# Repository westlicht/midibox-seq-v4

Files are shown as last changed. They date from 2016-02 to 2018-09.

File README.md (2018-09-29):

# midibox-seq-v4

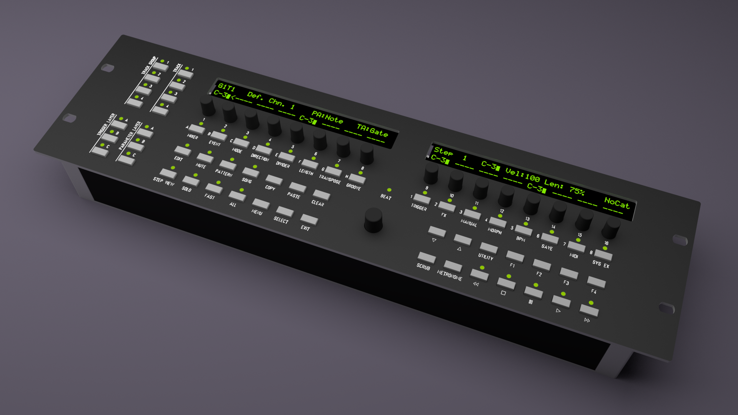
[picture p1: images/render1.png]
Rendering


This repository contains some documentation and data created during the build process of a MIDIBox SEQ V4. Please note that I'm **not** the original author of the project. The original project is hosted at http://ucapps.de

## MIDIbox PCBs

I ordered the PCBs from http://midiboxshop.bigcartel.com

Here is the list:

- 1x [CORE STMF32 BOARD](http://midiboxshop.bigcartel.com/product/core-stm32f4-board)
- 2x [MIDI I/O MODULE BOARD](http://midiboxshop.bigcartel.com/product/midi-i-o-module-board)
- 1x [DOUT MODULE BOARD](http://midiboxshop.bigcartel.com/product/dout-module-board)
- 1x [AOUT_NG BOARD](http://midiboxshop.bigcartel.com/product/aout_ng-module-board)
- 1x [SEQ CS BOARD](http://midiboxshop.bigcartel.com/product/seq-cs-board)

## Parts

I ordered the parts from [TME](http://www.tme.eu/en), [Reichelt](http://www.reichelt.com/), [DigiKey](http://www.digikey.com) and [Mouser](http://www.mouser.com). Sourcing the parts is a little painful. In addition, for some parts there are a few (or many) options. The following are a few notes on the parts I've chosen for the build:

- ALPS [Reichelt](https://www.reichelt.com/Drehimpulsgeber/STEC12E08/3/index.html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)
TODO

## Custom PCB

As I wanted to have nice backpanel as well as Ethernet support, I designed a PCB with the following additional features:

- Ethernet via SPI (based on http://ucapps.de/mbhp_eth.html)
- SD card socket
- USB connector
- +/- 12V DC/DC converter for the AOUT power supply

The PCB was designed in [KiCad](http://kicad-pcb.org/) and produced by [OSH Park](https://oshpark.com/). The PCB is available [here](https://oshpark.com/shared_projects/DuxxcHS7). Feel free to order your own!

Here is the bill of materials:

| Part | Description | Supplier |
| --- | --- | --- |
| C1, C4, C5, C6, C8, C9, C10, C11, C14, C15 | Ceramic Capacitor 100 nF |
| C2, C3 | Ceramic Capacitor 18 pF |
| C7 | Tantal Capacitor 10 uF |
| C12, C16 | Polarized Capacitor 47 uF |
| C13 | Polarized Capacitor 100 uF |
| R1 | Resistor 2.32 kOhm |
| R2, R3, R4, R5 | Resistor 49.9 Ohm |
| R6, R7 | Resistor 220 Ohm |
| L1 | Ferrit Bead 10 uH | [Reichelt](https://www.reichelt.com/Filter/BEAD-10-60/3/index.html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) |
| Y1 | Crystal 25 MHz | [Reichelt](https://www.reichelt.com/Quarze/25-0000-HC49U-S/3/index.html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) |
| IC1 | ENC28J60-I/SP DIP | [DigiKey](http://www.digikey.ch/product-detail/de/ENC28J60-I%2FSP/ENC28J60-I%2FSP-ND/1680061) |
| P1 | USB B connector | TODO |
| U1 | 3M SD-RSMT-2-MQ | [Mouser](http://www.mouser.ch/ProductDetail/3M-Electronic-Solutions-Division/SD-RSMT-2-MQ/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) |
| U2 | NMH0512SC ([datasheet](http://www.farnell.com/datasheets/1790401.pdf)) | [Reichelt](https://www.reichelt.com/Wandler-Module-DC-DC/NMH0512SC/3/index.html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)
| U3 | Pulse J0026D21E | [Mouser](http://www.mouser.ch/search/ProductDetail.aspx?r=673-J0026D21E) |

## Frontpanel / Case

Frontpanel

Backpanel

The frontpanel is based on the [Wilba frontpanel](http://www.midibox.org/dokuwiki/doku.php?id=wilba_mb_seq). I only adjusted some of the drillings in addition to moving things around slightly to make sure everything fits within the case. The backpanel was designed from scratch in order to fit nicely with the MIDI I/O PCBs as well as my own PCB. In addition, a DSUB-25 connector is used for the analog bus and a few important analog outputs are available seperatly on 3.5 mm jacks. The rest of the case are just basic aluminium panels and everything is hold together by enclosure profiles. The case can be ordered from [Schaeffer AG](https://www.schaeffer-ag.de). All required files are available in the ``case`` directory.

## Notes

## Links

## Build Images

Build
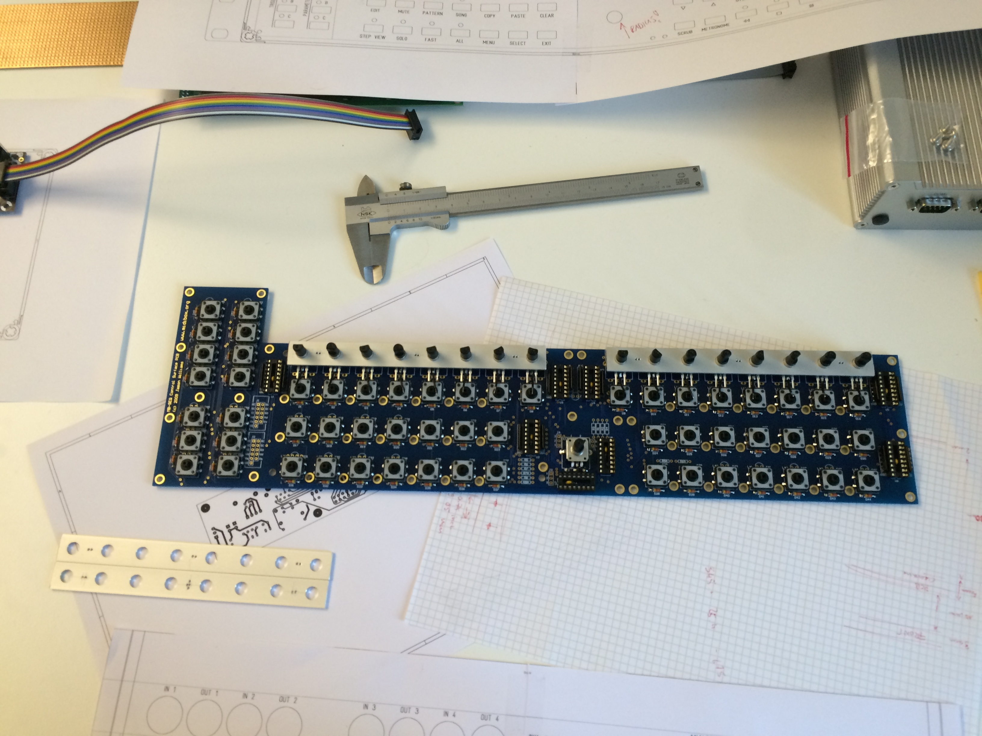
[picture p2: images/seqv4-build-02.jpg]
Build

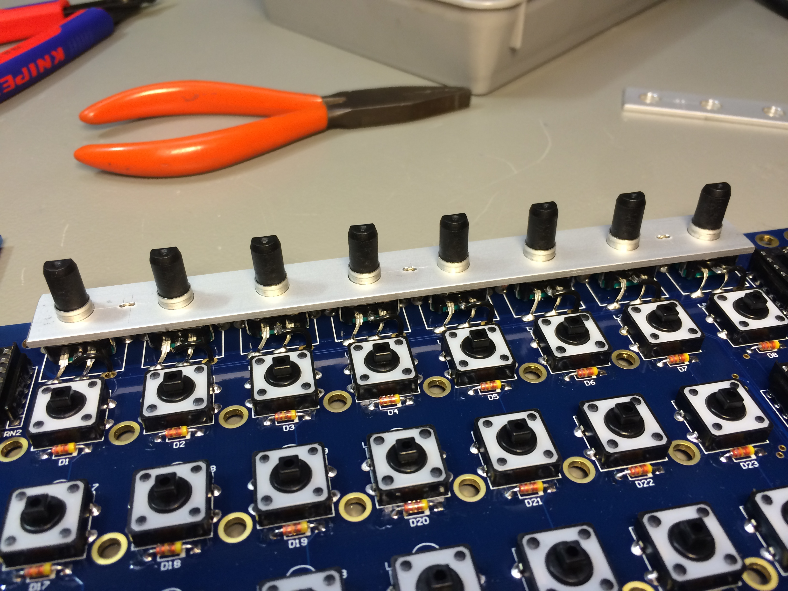
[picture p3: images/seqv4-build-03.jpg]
Build

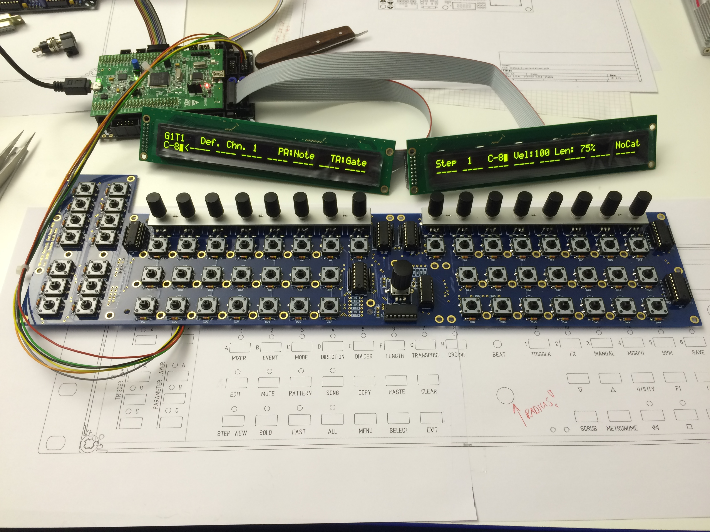
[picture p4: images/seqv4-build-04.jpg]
Build

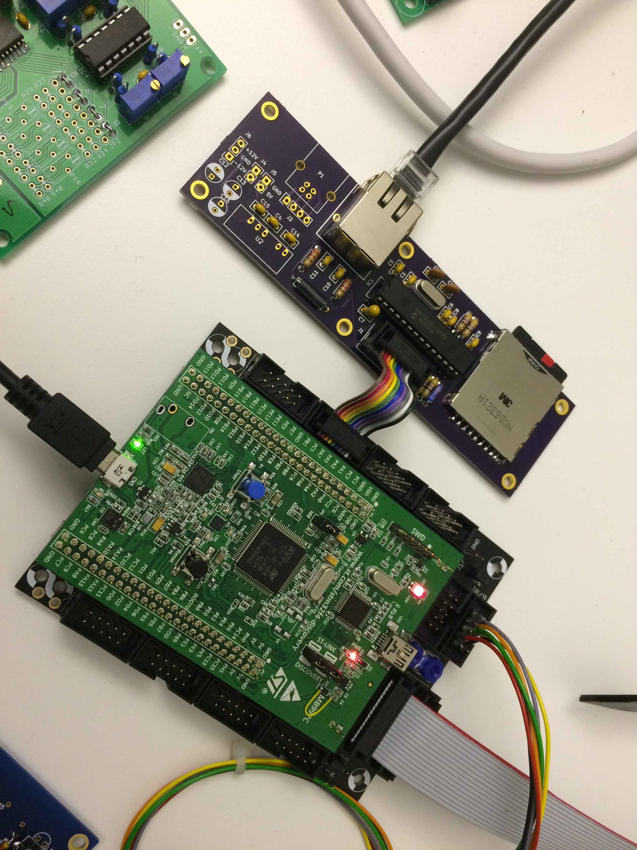
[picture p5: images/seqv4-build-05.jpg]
Build

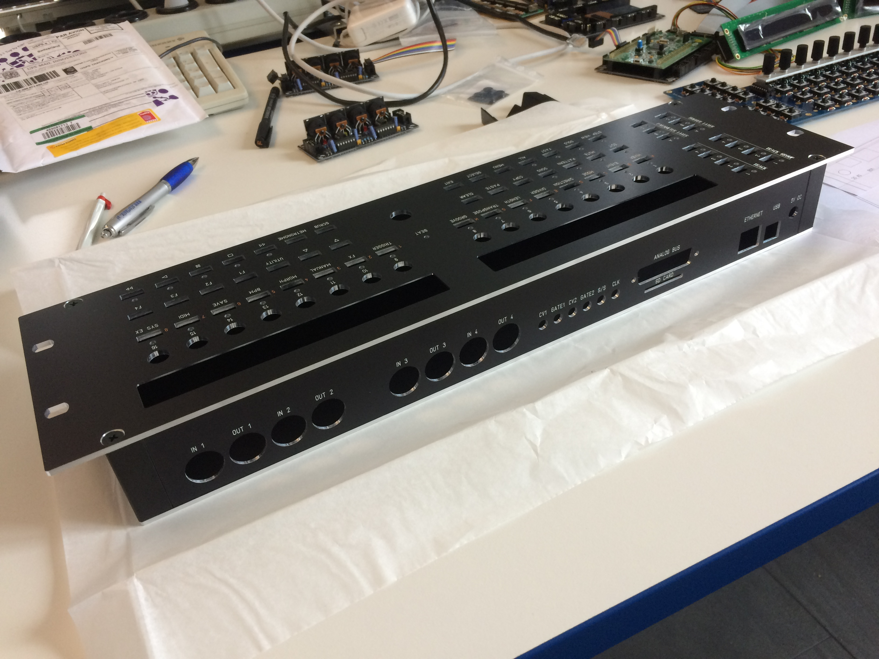
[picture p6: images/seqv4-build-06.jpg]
Build

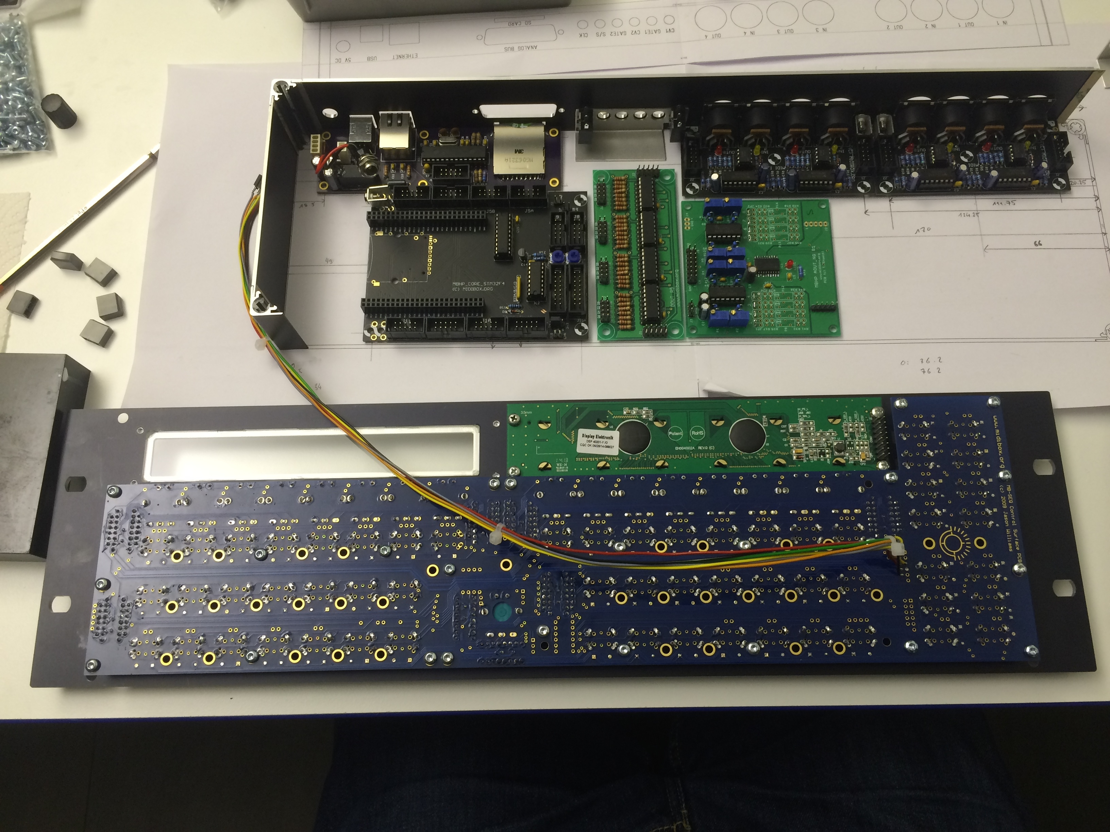
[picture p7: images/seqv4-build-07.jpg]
Build

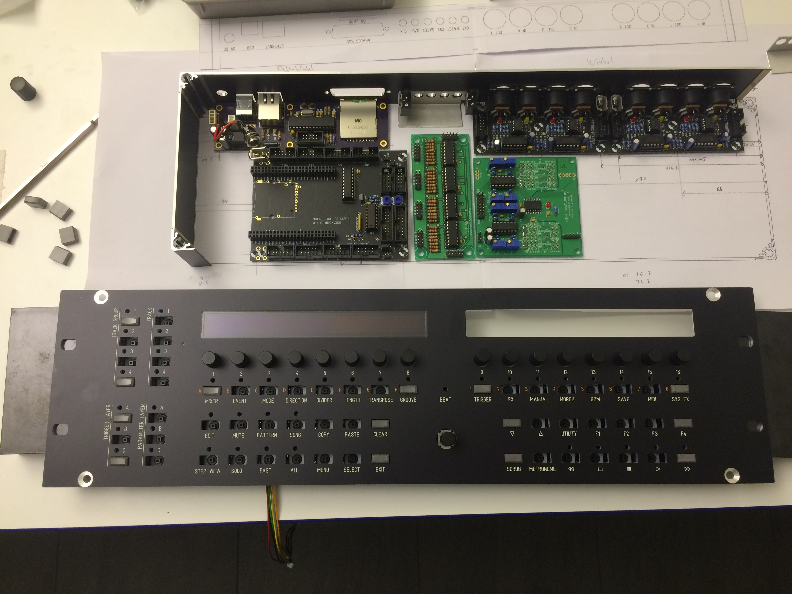
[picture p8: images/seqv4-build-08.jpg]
Build

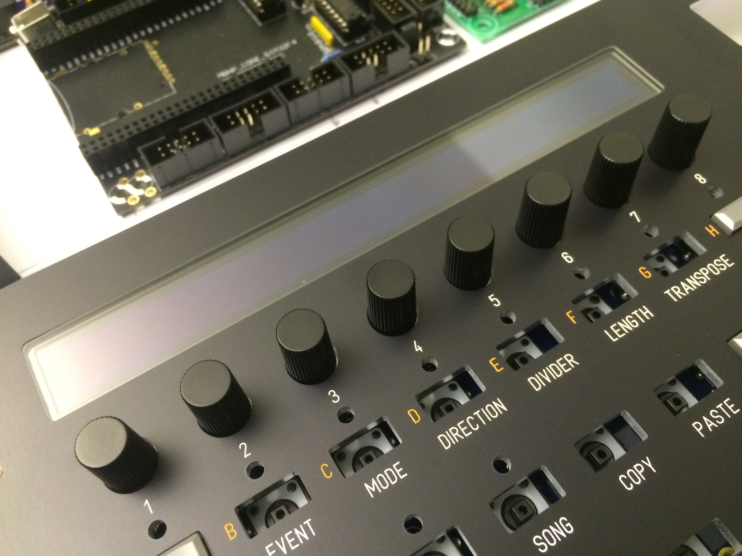
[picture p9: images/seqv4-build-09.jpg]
Build

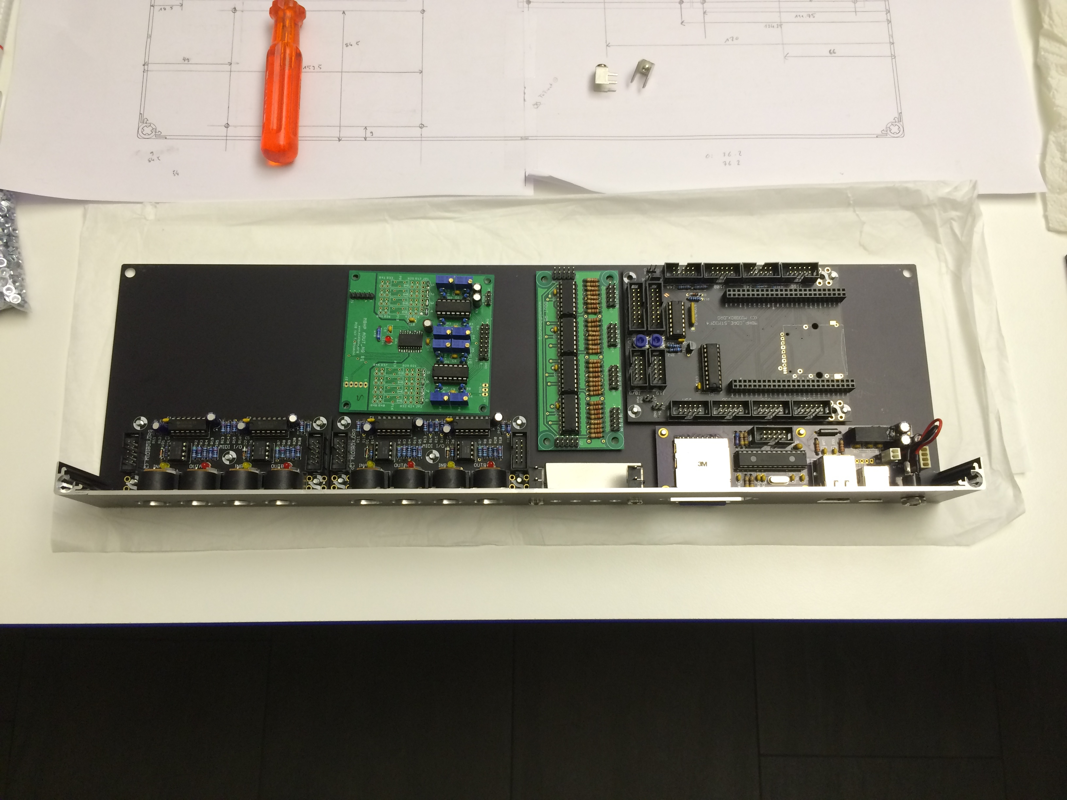
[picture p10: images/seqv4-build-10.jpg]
Build

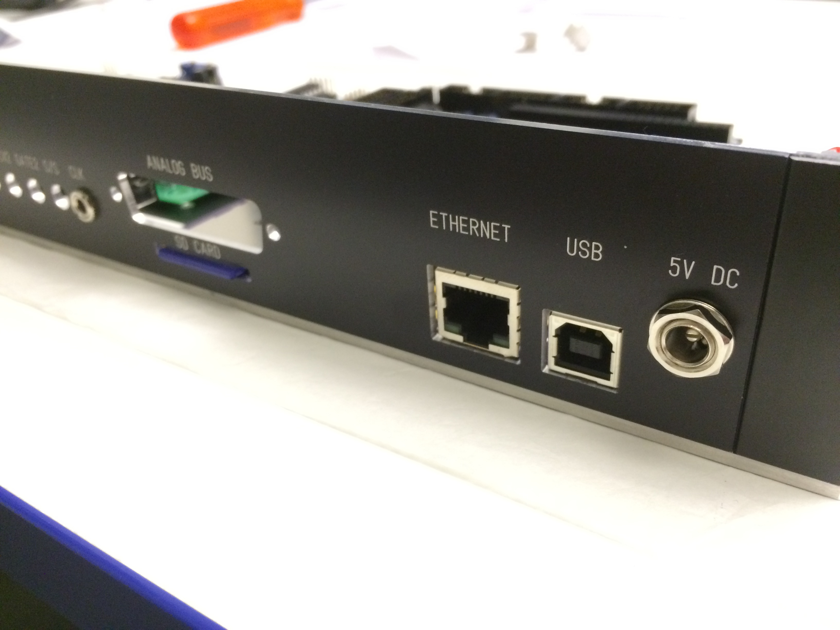
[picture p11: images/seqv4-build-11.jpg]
Build

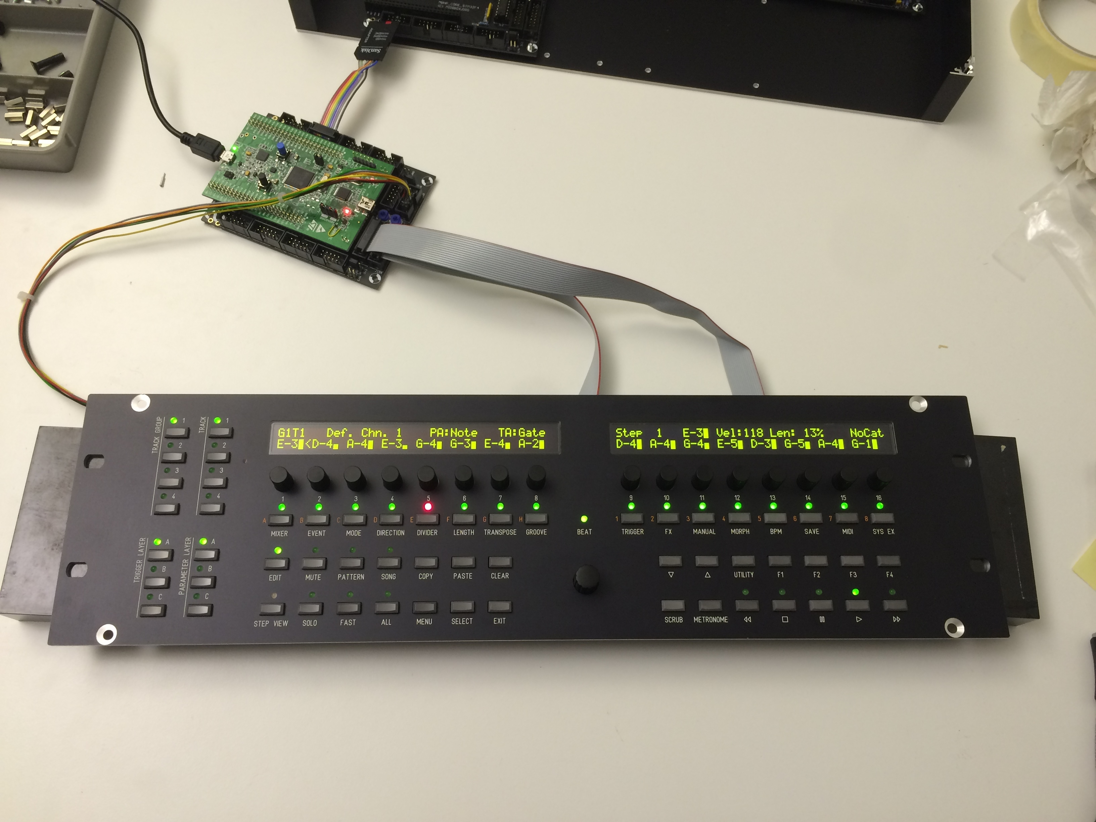
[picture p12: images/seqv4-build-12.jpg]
Build

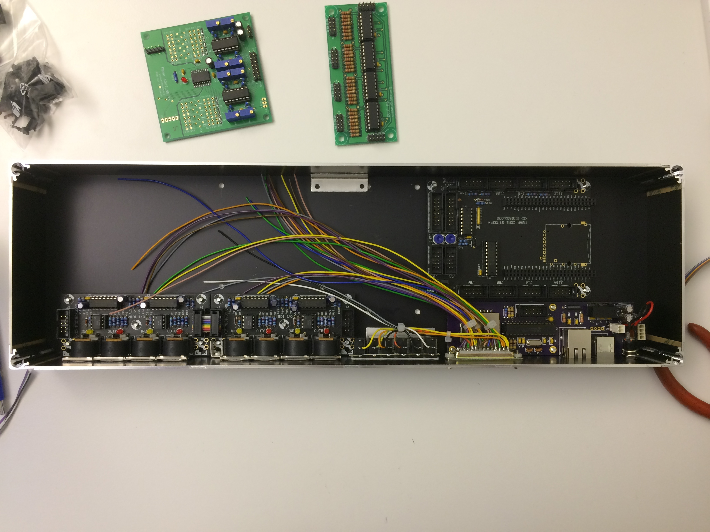
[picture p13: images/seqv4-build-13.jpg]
Build

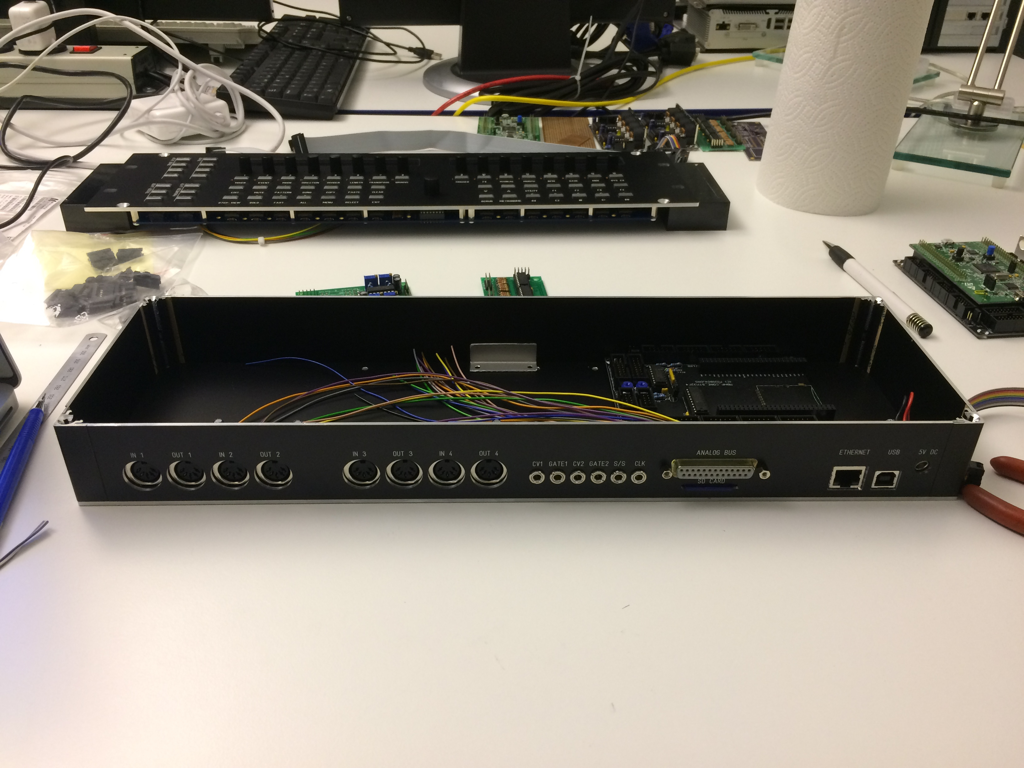
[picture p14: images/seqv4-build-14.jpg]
Build

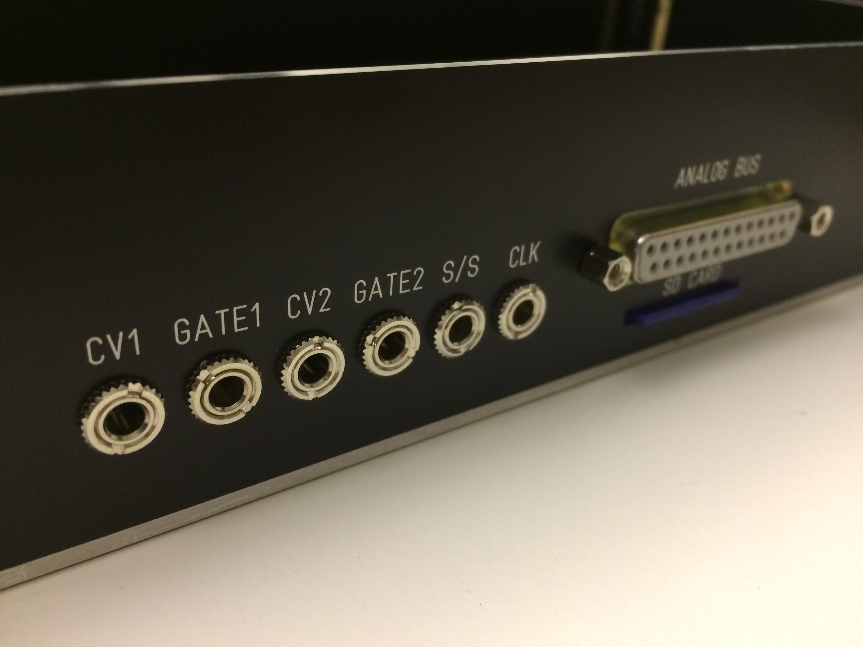
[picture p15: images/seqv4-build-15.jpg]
Build

Build
Build

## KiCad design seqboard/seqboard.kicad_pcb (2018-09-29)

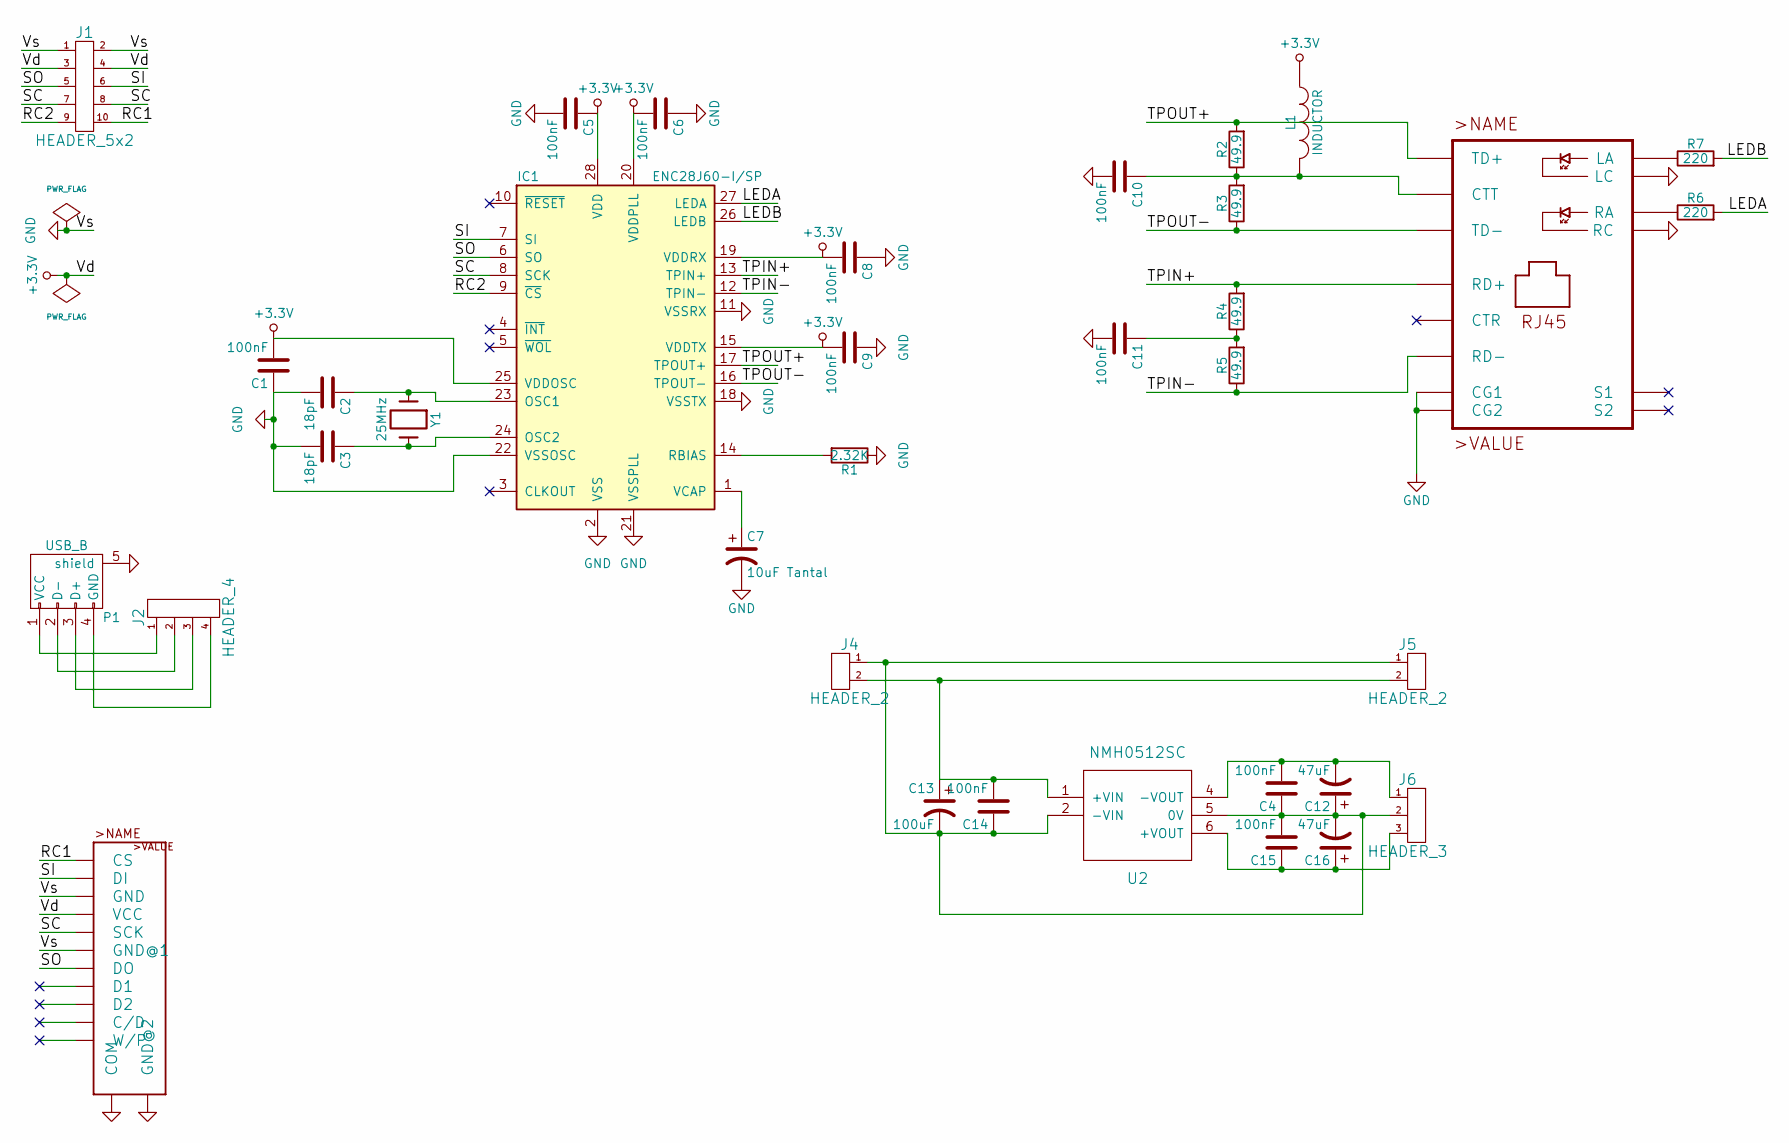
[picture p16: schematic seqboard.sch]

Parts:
C1, C4, C5, C6, C8, C9, C10, C11, C14, C15: 100nF; cnp_3mm_disc
C2, C3: 18pF; cnp_3mm_disc
C7: 10uF Tantal; cnp_3mm_disc
C12, C16: 47uF; C_Radial_D5_L6_P2.5
C13: 100uF; C_Radial_D5_L6_P2.5
IC1: ENC28J60-I/SP; DIP-28_W7.62mm_LongPads
J1: HEADER_5x2; IDC_Header_Straight_10pins
J2: HEADER_4; Pin_Header_Straight_1x04
J4, J5: HEADER_2; Pin_Header_Straight_1x02
J6: HEADER_3; Pin_Header_Straight_1x03
L1: INDUCTOR; R5
P1: USB_B
R1: 2.32K; Resistor_Horizontal_RM7mm
R2, R3, R4, R5: 49.9; Resistor_Horizontal_RM7mm
R6, R7: 220; Resistor_Horizontal_RM7mm
U1: SD-SOCKET-3M_SD-SOCKET-3M; SD-SOCKET-3M
U2: NMH0512SC
U3: J0026D21E_J0-A/B/F; J0-A%2fB%2fF
Y1: 25MHz; Crystal_HC49-U_Vertical

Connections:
+3.3V: C1.2, C5.1, C6.2, C8.2, C9.2, IC1.15 (VDDTX), IC1.19 (VDDRX), IC1.20 (VDDPLL), IC1.25 (VDDOSC), IC1.28 (VDD), J1.3, J1.4, L1.1, U1.4 (VCC)
/LEDA: IC1.27 (LEDA), R6.2
/LEDB: IC1.26 (LEDB), R7.2
/RC1: J1.10, U1.1 (CS)
/RC2: IC1.9 (~CS), J1.9
/SC: IC1.8 (SCK), J1.7, J1.8, U1.5 (SCK)
/SI: IC1.7 (SI), J1.6, U1.2 (DI)
/SO: IC1.6 (SO), J1.5, U1.7 (DO)
/TPIN+: IC1.13 (TPIN+), R4.2, U3.7 (RD+)
/TPIN-: IC1.12 (TPIN-), R5.1, U3.8 (RD-)
/TPOUT+: IC1.17 (TPOUT+), R2.2, U3.1 (TD+)
/TPOUT-: IC1.16 (TPOUT-), R3.1, U3.2 (TD-)
GND: C1.1, C2.2, C3.2, C5.2, C6.1, C7.2, C8.1, C9.1, C10.2, C11.2, IC1.2 (VSS), IC1.11 (VSSRX), IC1.18 (VSSTX), IC1.21 (VSSPLL), IC1.22 (VSSOSC), J1.1, J1.2, P1.5 (shield), R1.1, U1.3 (GND), U1.6 (GND@1), U1.GND@ (COM), U3.4 (CG1), U3.5 (CG2), U3.10 (LC), U3.11 (RC)
unnamed: C2.1, IC1.23 (OSC1), Y1.1
unnamed: C3.1, IC1.24 (OSC2), Y1.2
unnamed: C7.1, IC1.1 (VCAP)
unnamed: C10.1, L1.2, R2.1, R3.2, U3.3 (CTT)
unnamed: C11.1, R4.1, R5.2
unnamed: C4.1, C12.1, C13.2, C14.1, C15.2, C16.2, J4.1, J5.1, J6.2, U2.2 (-VIN), U2.5 (0V)
unnamed: C4.2, C12.2, J6.1, U2.4 (-VOUT)
unnamed: C13.1, C14.2, J4.2, J5.2, U2.1 (+VIN)
unnamed: C15.1, C16.1, J6.3, U2.6 (+VOUT)
unnamed: IC1.14 (RBIAS), R1.2
unnamed: J2.1, P1.1 (VCC)
unnamed: J2.2, P1.2 (D-)
unnamed: J2.3, P1.3 (D+)
unnamed: J2.4, P1.4 (GND)
unnamed: R6.1, U3.12 (RA)
unnamed: R7.1, U3.9 (LA)

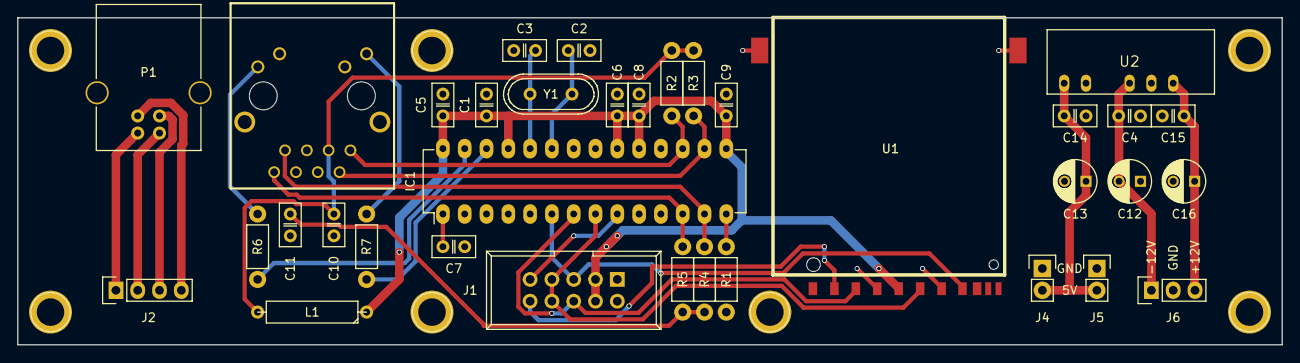
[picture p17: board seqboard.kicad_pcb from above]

Board: 2 copper layers, 147.3 x 38.1 mm, 35 parts (0 on the bottom side), 29 nets.

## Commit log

2016-02-24 added files for case
2018-09-29 added custom pcb design files
    [seqboard-variant.GBL, seqboard-variant.GBO, seqboard-variant.GBS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]
